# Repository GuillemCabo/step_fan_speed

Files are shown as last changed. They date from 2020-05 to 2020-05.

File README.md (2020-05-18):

# step\_fan\_speed

## Description 
Simple PCB to control computer fan speed with a atinny88

The board runs out of the fan 12V, step down to 3.3V with an LDO.

It provides a PWM header in and PWM out. The MCU is able to intercept the
signal of the tachometer and generated a new PWM signal.

## Usage 
The uart is accesible through a two pin headeris. External FTDI bridge is required
if you want to connect it to the computer.

The board is programmed  thorugh ISP with a Tag-connect cable or UART if a
bootloader if it has been previously programmed.

## IO
* 3 DIP switches
* 1 Push button
* 2 LEDs 
* NTC sensor.
* I2C port (As SMD pads)
* PMW in
* PWM out
* UART

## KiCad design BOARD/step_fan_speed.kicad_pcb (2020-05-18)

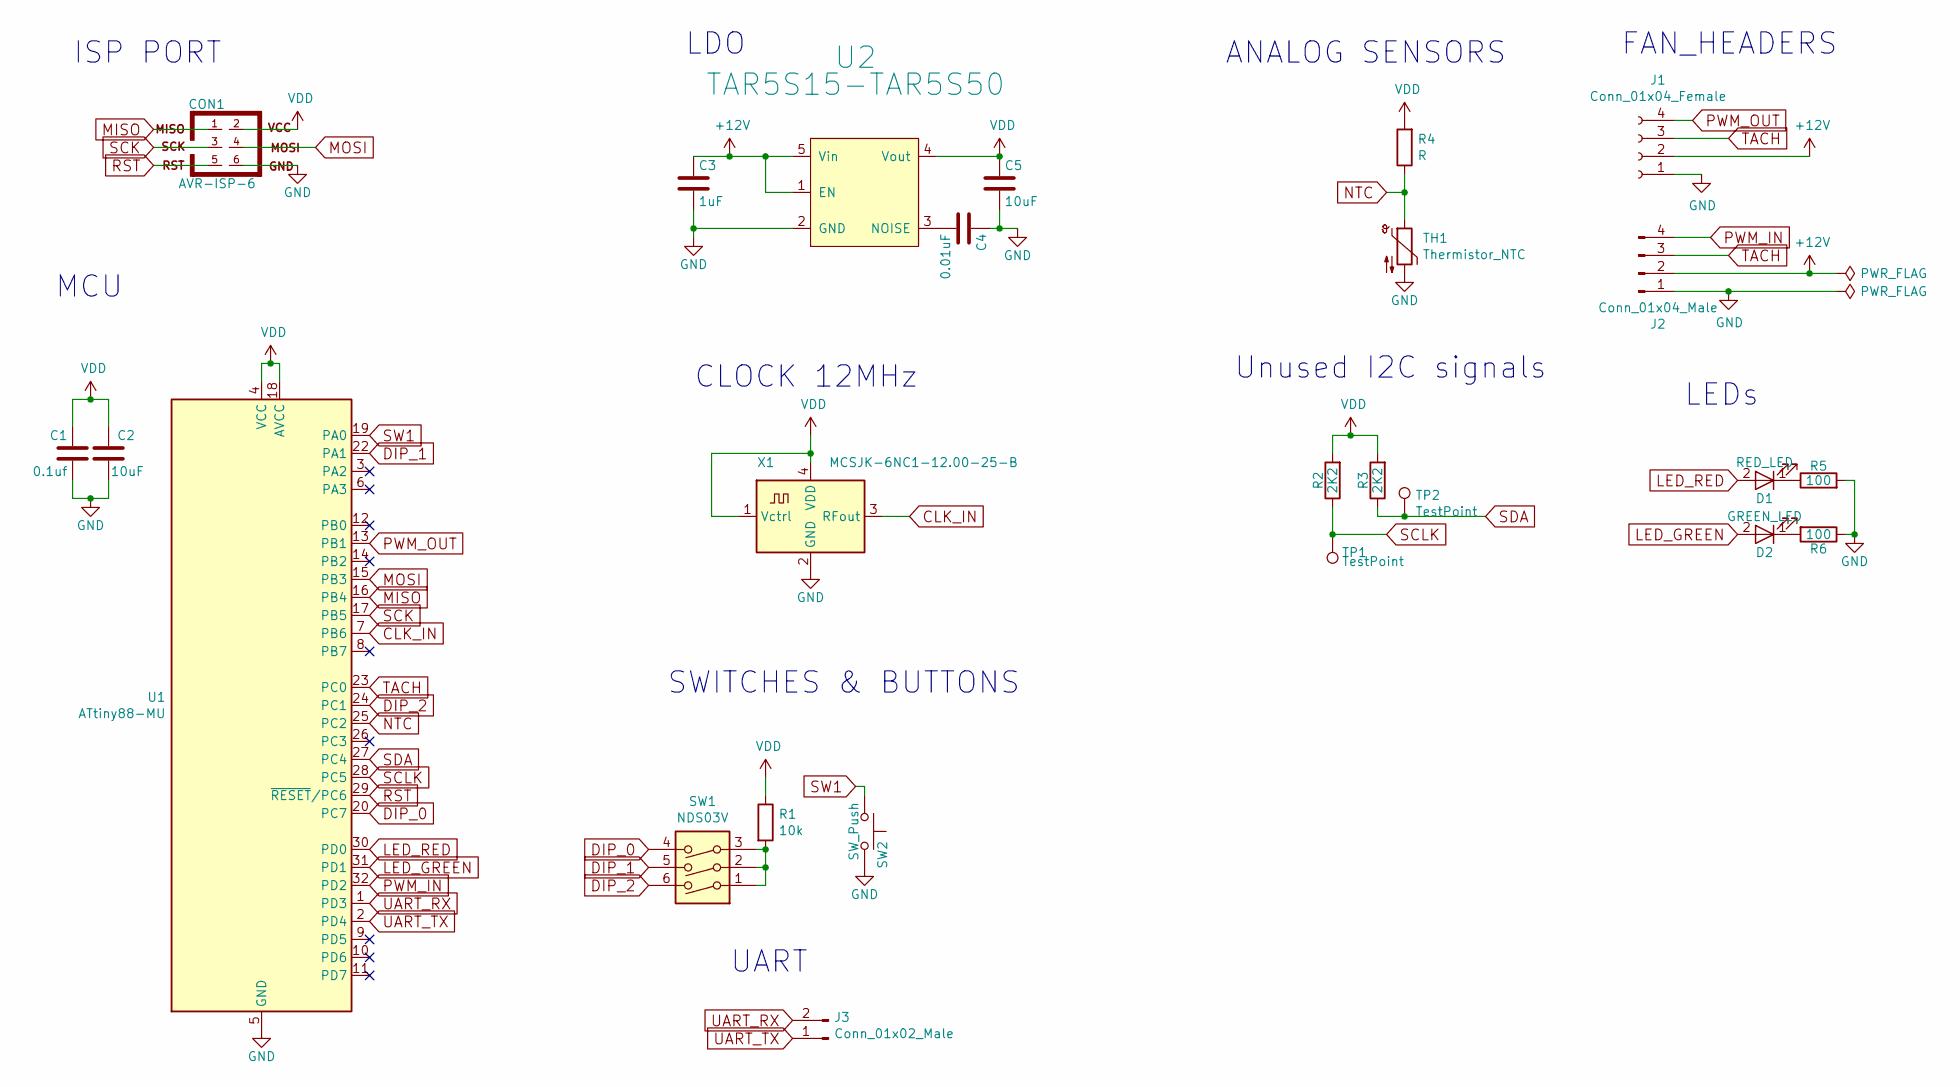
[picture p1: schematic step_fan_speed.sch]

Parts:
C1: 0.1uf; C_0603_1608Metric; MPN C0603C104J5RACTU; FARNELL # 2409037
C2: 10uF; C_0805_2012Metric; MPN C0805X106K9RACTU; FARNELL # 2776900
C3: 1uF; C_0603_1608Metric; MPN C0603C105K9RACTU; FARNELL # 1865556
C4: 0.01uF; C_0603_1608Metric; MPN C0603C105K9RACTU; FARNELL # 1865556
C5: 10uF; C_0805_2012Metric; MPN C0603C105K9RACTU; FARNELL # 1865556
CON1: AVR-ISP-6; Tag-Connect_TC2030-IDC-NL_2x03_P1.27mm_Vertical; MPN NONE; FARNELL # NONE
D1: RED_LED; KPA-1606; MPN KPA-1606SURCK; FARNELL # 2290358
D2: GREEN_LED; KPA-1606; MPN KPA-1606CGCK; FARNELL # 2290360
J1: Conn_01x04_Female; PinSocket_1x04_P2.54mm_Horizontal
J2: Conn_01x04_Male; PinHeader_1x04_P2.54mm_Horizontal
J3: Conn_01x02_Male; PinHeader_1x02_P2.54mm_Horizontal
R1: 10k; R_0603_1608Metric; MPN CRCW1206100RFKEA
R2, R3: 2K2; R_0603_1608Metric; MPN MC0063W060354K7; FARNELL # 9332154
R4: R; R_0603_1608Metric
R5, R6: 100; R_0603_1608Metric; FARNELL # 1469752
SW1: NDS03V; SW_DIP_SPSTx03_Slide_9.78x9.8mm_W7.62mm_P2.54mm; MPN NDS03V
SW2: SW_Push; SW_Push_1P1T_NO_CK_KSC7xxJ; MPN EVQPUK02K; FARNELL # 2079467
TH1: Thermistor_NTC; R_Axial_DIN0204_L3.6mm_D1.6mm_P2.54mm_Vertical
TP1, TP2: TestPoint; TestPoint_Pad_1.5x1.5mm
U1: ATtiny88-MU; QFN-32-1EP_5x5mm_P0.5mm_EP3.1x3.1mm; MPN ATTINY88-MU; FARNELL # 1748549
U2: TAR5S15-TAR5S50; SOT-23-5_HandSoldering
X1: MCSJK-6NC1-12.00-25-B; Oscillator_SMD_EuroQuartz_XO91-4Pin_7.0x5.0mm_HandSoldering

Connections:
+12V: C3.1, J1.2, J2.2, U2.1 (EN), U2.5 (Vin)
CLK_IN: U1.7 (PB6), X1.3 (RFout)
DIP_0: SW1.4, U1.20 (PC7)
DIP_1: SW1.5, U1.22 (PA1)
DIP_2: SW1.6, U1.24 (PC1)
GND: C1.2, C2.2, C3.2, C4.1, C5.2, CON1.6, J1.1, J2.1, R5.2, R6.1, SW2.2, TH1.2, U1.5 (GND), U1.21 (GND), U1.33 (GND), U2.2 (GND), X1.2 (GND)
LED_GREEN: D2.2 (A), U1.31 (PD1)
LED_RED: D1.2 (A), U1.30 (PD0)
MISO: CON1.1, U1.16 (PB4)
MOSI: CON1.4, U1.15 (PB3)
NTC: R4.1, TH1.1, U1.25 (PC2)
unnamed: C4.2, U2.3 (NOISE)
unnamed: D1.1 (K), R5.1
unnamed: D2.1 (K), R6.2
unnamed: R1.2, SW1.1, SW1.2, SW1.3
PWM_IN: J2.4, U1.32 (PD2)
PWM_OUT: J1.4, U1.13 (PB1)
RST: CON1.5, U1.29 (~RESET~/PC6)
SCK: CON1.3, U1.17 (PB5)
SCLK: R2.1, TP1.1, U1.28 (PC5)
SDA: R3.1, TP2.1, U1.27 (PC4)
SW1: SW2.1, U1.19 (PA0)
TACH: J1.3, J2.3, U1.23 (PC0)
UART_RX: J3.2, U1.1 (PD3)
UART_TX: J3.1, U1.2 (PD4)
VDD: C1.1, C2.1, C5.1, CON1.2, R1.1, R2.2, R3.2, R4.2, U1.4 (VCC), U1.18 (AVCC), U2.4 (Vout), X1.1 (Vctrl), X1.4 (VDD)

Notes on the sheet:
LDO
ISP PORT
FAN_HEADERS
Unused I2C signals
LEDs
SWITCHES & BUTTONS
ANALOG SENSORS
MCU
CLOCK 12MHz
UART

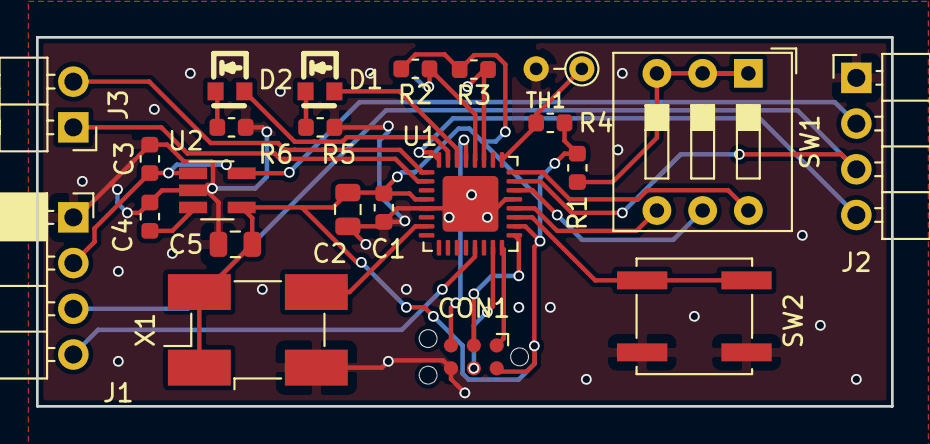
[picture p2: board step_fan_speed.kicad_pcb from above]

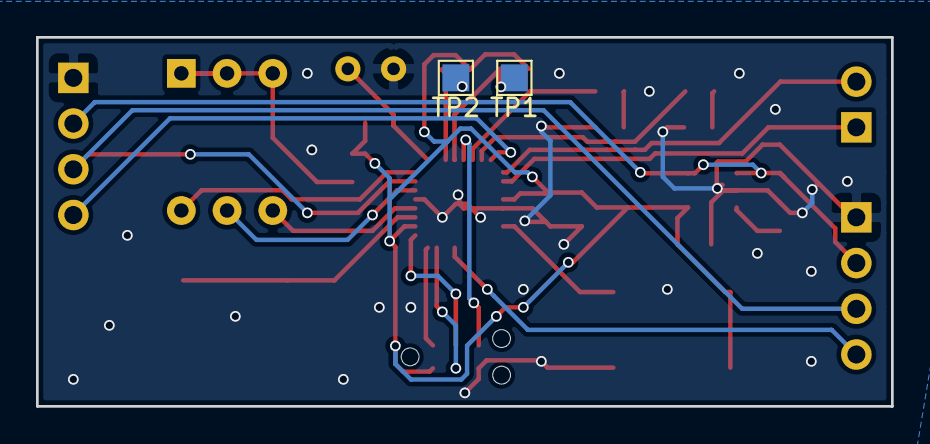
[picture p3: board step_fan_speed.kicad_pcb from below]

Board: 2 copper layers, 47.5 x 20.5 mm, 25 parts (2 on the bottom side), 26 nets.
